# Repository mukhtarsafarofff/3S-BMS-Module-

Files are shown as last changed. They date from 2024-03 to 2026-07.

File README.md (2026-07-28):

(ENG)  The function of this circuit is to charge the batteries, protect them for overvoltage, limit the current and also balance the batteries in case of more than one cell. Lithium ion or LiPo batteries are verry popular, especially with makers like us for small robots, portable devices, RC toy cars and drones and so on. But these batteries are also very sensible and dangerous. If we don’t control the process of charging anddischarging of such batteries, they will stop working or worse. The battery cells can swell and even explode from overcharging, and a deep discharge can make the battery fail. That’s why these batteries should go together with a battery management system unit or BMS. This will control the voltage and current from the battery and keep them safe. Usually, the nominal voltage of a LIPO battery is 3.8 volts and 4.2V when fully charged. As soon as the battery cell will reach this value, the charging process should stop and that’s what this circuit should do.  When we have only one cell, we only care about the maximum voltage and the current limit to protect the battery. But when we have a battery pack of more than 1 cell, so 2S, 3S and so on, we also need to balance the value of each individual cell. We have a PNP transistor connected in series with 4 diodes that will simulate a load. At the base of the transistor, we have a ZENNER reference diode (TL431) which will get open at a certain voltage value and by that connects ground to the transistors base and when the transistor is active, we bypass the battery and waste the power on the diodes instead. This ZENNER diode is the TL431 and it has a reference pin, so by adjusting the potentiometer we can set this reference to be at 4.2V, that’s how we select when the charging process will stop. I supply it with 4.2V from my power supply. I connect my multimeter at the output and using the potentiometer, we first fix the threshold value to around 4.16V, some value below 4.2V. I will use a battery which is discharged and below 4.2V (it was 3.8V). When I connect it to the charger, the LED is turned off. We have a current flow of around 450 mA and the battery is getting charged up. After some time, when we get above 4.16V the LED will turn ON so the charging process is complete. Current is now flowing through the diodes and transistor and we skip the battery, so the cell is protected for over voltage. I measure battery and it is 4.11 volts. We can take this simple circuit and merge it in series other identical circuits. With this circuit, we can charge a 3S battery for exampleand all individual cells will stop charging at 4.2V. The only downside, is the efficiency and heat dissipation. 

(DEU) Die Funktion dieses Schaltkreises besteht darin, die Batterien zu laden, sie vor Überspannung zu schützen, den Strom zu begrenzen und die Batterien bei mehr als einer Zelle auszugleichen. Lithium-Ionen- oder LiPo-Batterien sind sehr beliebt, besonders bei Machern wie uns für kleine Roboter, tragbare Geräte, ferngesteuerte Spielzeugautos und Drohnen und so weiter. Aber diese Batterien sind auch sehr empfindlich und gefährlich. Wenn wir den Lade- und Entladevorgang solcher Batterien nicht kontrollieren, werden sie nicht mehr funktionieren oder schlimmer.  Die Batteriezellen können sich aufblähen und sogar durch Überladung explodieren, und eine Tiefentladung kann die Batterie unbrauchbar machen. Deshalb sollten diese Batterien immer mit einem Batterie-Management-System (BMS) verwendet werden. Dieses kontrolliert die Spannung und den Strom der Batterie und hält sie sicher. Normalerweise beträgt die Nennspannung einer LiPo-Batterie 3,8 Volt und 4,2V, wenn sie vollständig geladen ist. Sobald die Batteriezelle diesen Wert erreicht, sollte der Ladevorgang gestoppt werden, und genau das soll dieser Schaltkreis tun. Wenn wir nur eine Zelle haben, kümmern wir uns nur um die maximale Spannung und die Strombegrenzung, um die Batterie zu schützen. Aber wenn wir einen Batteriepack mit mehr als einer Zelle haben, also 2S, 3S und so weiter, müssen wir auch den Wert jeder einzelnen Zelle ausgleichen. Wir haben einen PNP-Transistor, der in Reihe mit 4 Dioden geschaltet ist, die eine Last simulieren.  An der Basis des Transistors haben wir eine Zener-Diode (TL431), die sich bei einem bestimmten Spannungswert öffnet und dadurch die Basis des Transistors mit Masse verbindet. Wenn der Transistor aktiv ist, umgehen wir die Batterie und verschwenden die Energie stattdessen an den Dioden. Diese Zener-Diode ist die TL431 und sie hat einen Referenzpin, sodass wir durch Einstellen des Potentiometers diese Referenz auf 4,2V setzen können. So wählen wir den Zeitpunkt, wann der Ladevorgang gestoppt wird. Ich versorge den Schaltkreis mit 4,2V von meinem Netzteil. Ich schließe mein Multimeter am Ausgang an und stelle mit dem Potentiometer zuerst den Schwellenwert auf etwa 4,16V ein, also etwas unter 4,2V. Ich werde eine Batterie verwenden, die entladen ist und unter 4,2V liegt (sie hatte 3,8V). Wenn ich sie an das Ladegerät anschließe, ist die LED ausgeschaltet. Wir haben einen Stromfluss von etwa 450 mA und die Batterie wird aufgeladen. Nach einiger Zeit, wenn wir über 4,16V kommen, wird die LED einschalten, sodass der Ladevorgang abgeschlossen ist. Der Strom fließt jetzt durch die Dioden und den Transistor, und wir umgehen die Batterie, sodass die Zelle vor Überspannung geschützt ist.

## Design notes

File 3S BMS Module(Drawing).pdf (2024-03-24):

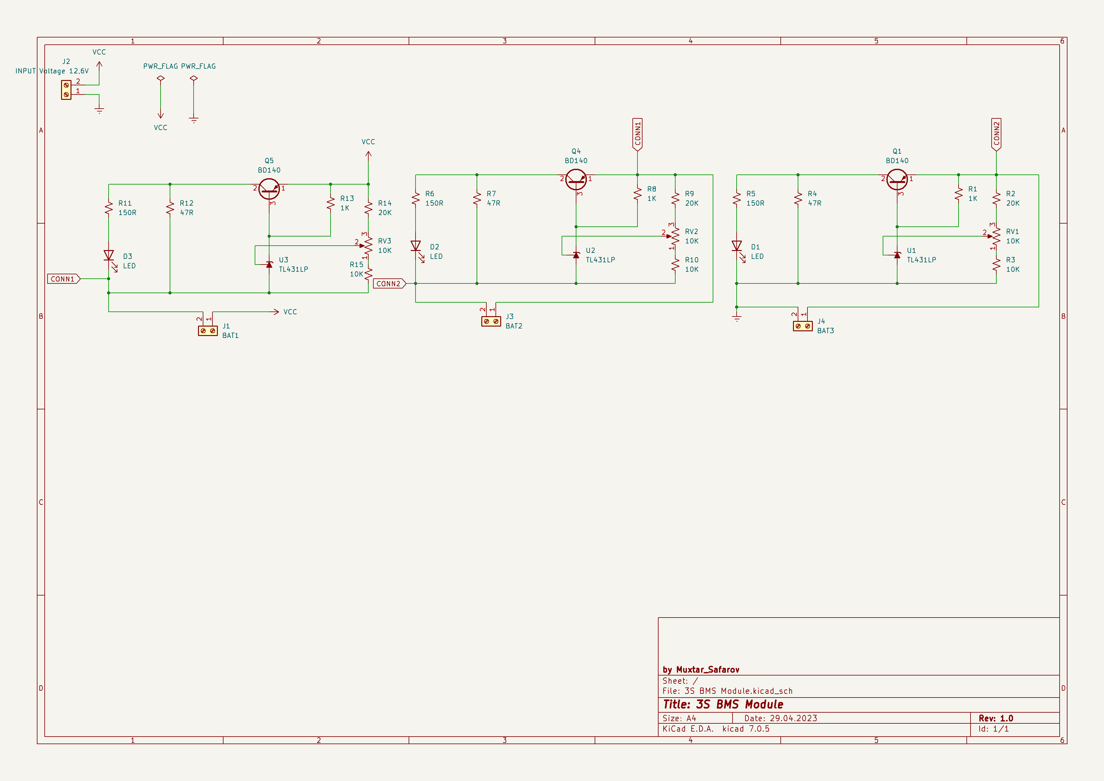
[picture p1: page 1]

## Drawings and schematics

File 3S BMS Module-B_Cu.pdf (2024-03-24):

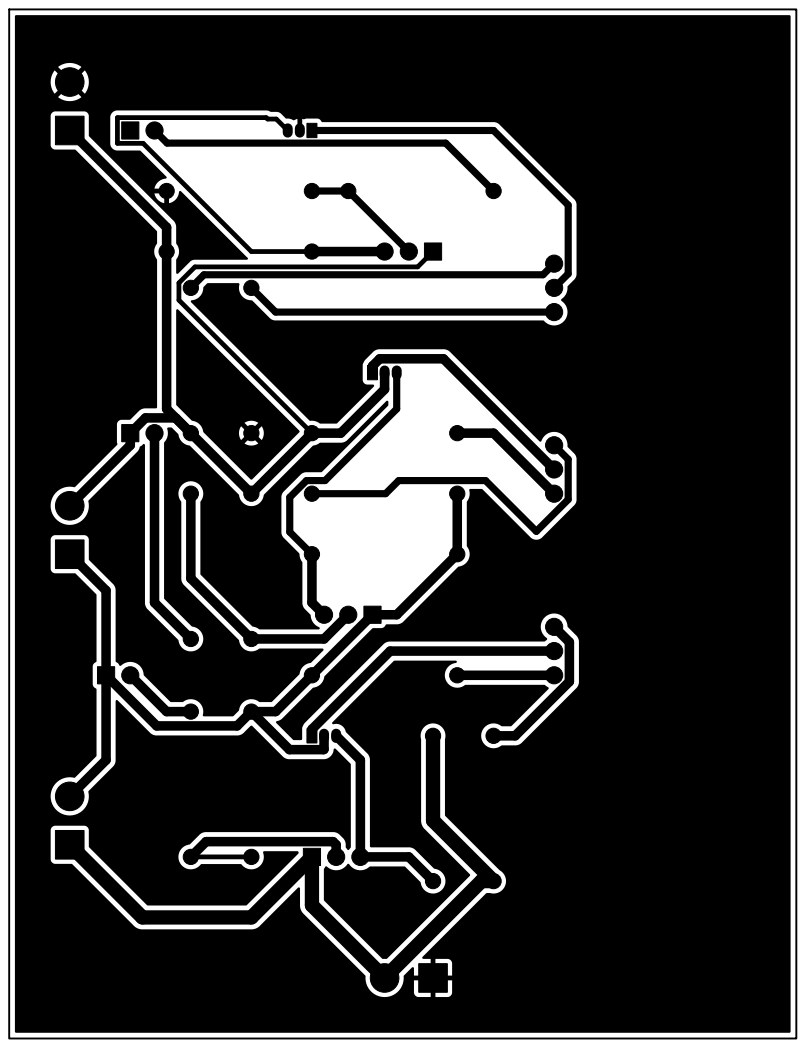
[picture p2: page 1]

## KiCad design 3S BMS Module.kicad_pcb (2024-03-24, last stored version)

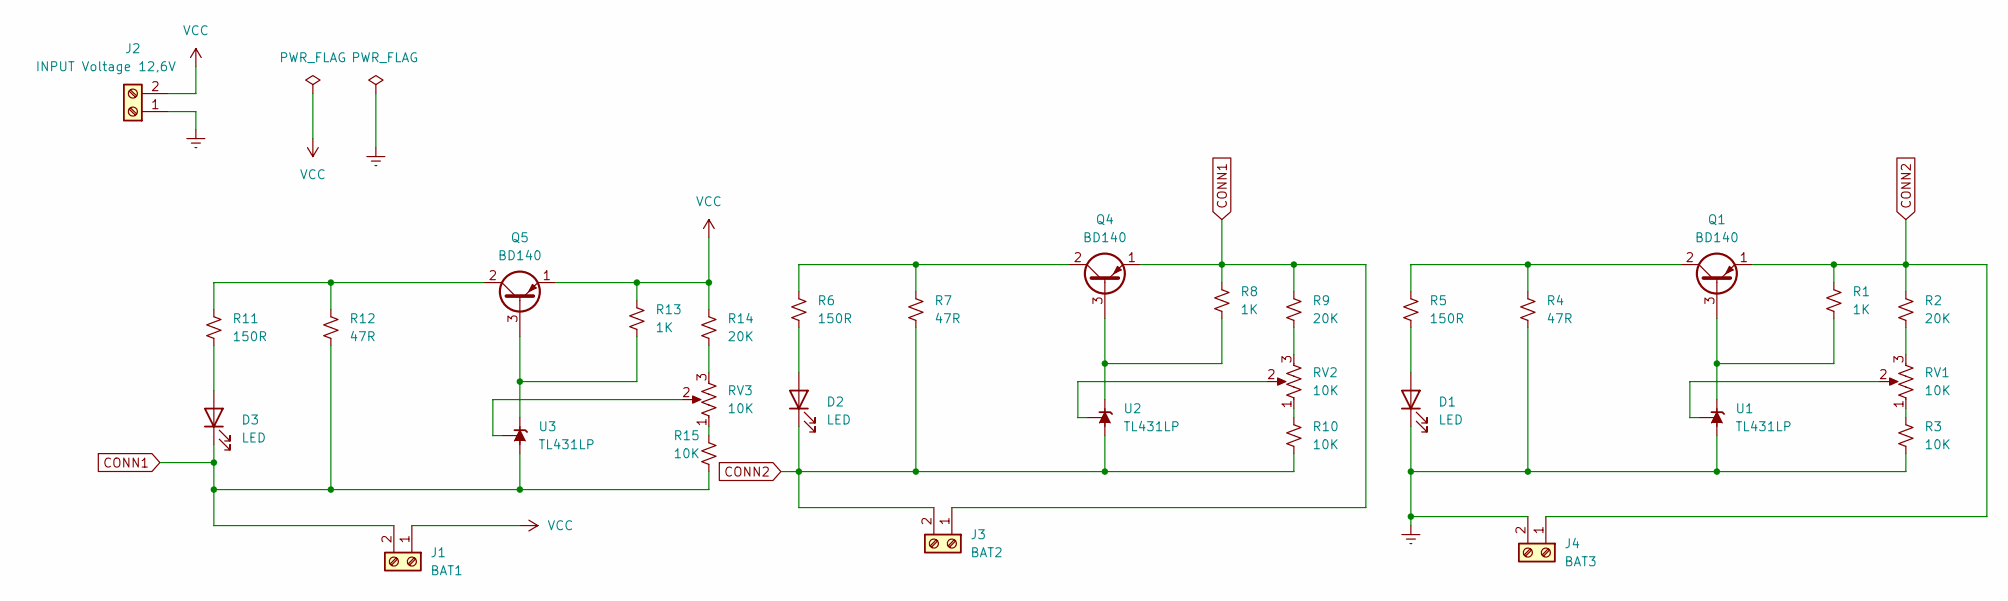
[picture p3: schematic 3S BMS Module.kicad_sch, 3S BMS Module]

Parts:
D1, D2, D3: LED; LED_D5.0mm
J1: BAT1; TerminalBlock_bornier-2_P5.08mm
J2: INPUT Voltage 12,6V; TerminalBlock_bornier-2_P5.08mm
J3: BAT2; TerminalBlock_bornier-2_P5.08mm
J4: BAT3; TerminalBlock_bornier-2_P5.08mm
Q1, Q4, Q5: BD140; TO-126-3_Vertical
R1, R8, R13: 1K; R_Axial_DIN0207_L6.3mm_D2.5mm_P15.24mm_Horizontal
R2, R9, R14: 20K; R_Axial_DIN0207_L6.3mm_D2.5mm_P15.24mm_Horizontal
R3, R10, R15: 10K; R_Axial_DIN0207_L6.3mm_D2.5mm_P15.24mm_Horizontal
R4, R7, R12: 47R; R_Axial_Power_L25.0mm_W9.0mm_P30.48mm
R5, R6, R11: 150R; R_Axial_DIN0207_L6.3mm_D2.5mm_P15.24mm_Horizontal
RV1, RV2, RV3: 10K; Potentiometer_Vishay_148-149_Single_Horizontal
U1, U2, U3: TL431LP; TO-92_Inline

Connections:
CONN1: D3.1 (K), J1.2, J3.1, Q4.1 (E), R8.1, R9.1, R12.2, R15.1, U3.2 (A)
CONN2: D2.1 (K), J3.2, J4.1, Q1.1 (E), R1.1, R2.1, R7.2, R10.1, U2.2 (A)
Earth: D1.1 (K), J2.1, J4.2, R3.1, R4.2, U1.2 (A)
unnamed: D1.2 (A), R5.2
unnamed: D2.2 (A), R6.2
unnamed: D3.2 (A), R11.2
unnamed: Q1.3 (B), R1.2, U1.3 (K)
unnamed: Q1.2 (C), R4.1, R5.1
unnamed: Q4.3 (B), R8.2, U2.3 (K)
unnamed: Q4.2 (C), R6.1, R7.1
unnamed: Q5.3 (B), R13.2, U3.3 (K)
unnamed: Q5.2 (C), R11.1, R12.1
unnamed: R2.2, RV1.3
unnamed: R3.2, RV1.1
unnamed: R9.2, RV2.3
unnamed: R10.2, RV2.1
unnamed: R14.2, RV3.3
unnamed: R15.2, RV3.1
unnamed: RV1.2, U1.1 (REF)
unnamed: RV2.2, U2.1 (REF)
unnamed: RV3.2, U3.1 (REF)
VCC: J1.1, J2.2, Q5.1 (E), R13.1, R14.1

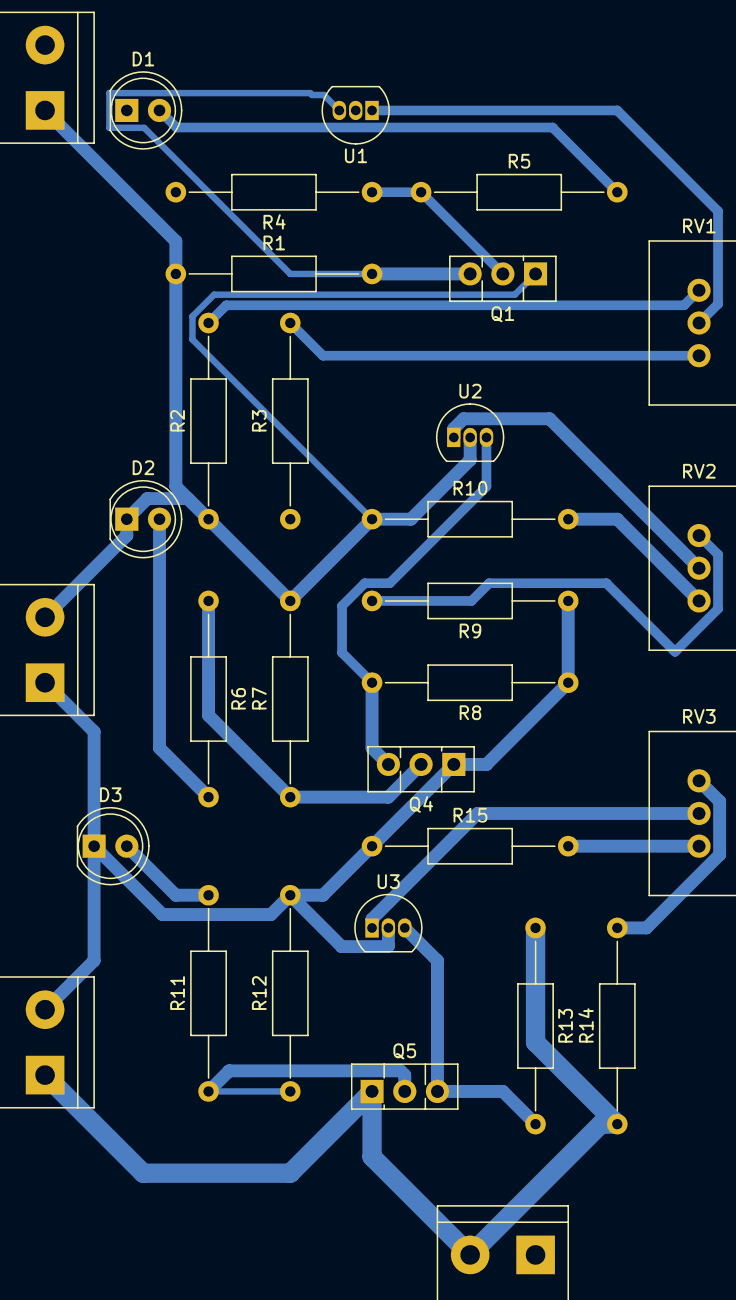
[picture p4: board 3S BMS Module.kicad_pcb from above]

Board: 2 copper layers, 31 parts (0 on the bottom side), 22 nets.
